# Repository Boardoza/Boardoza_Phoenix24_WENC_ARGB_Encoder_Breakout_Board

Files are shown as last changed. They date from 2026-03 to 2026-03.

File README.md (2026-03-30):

# Boardoza Phoenix24-WENC Breakout Board

The **Boardoza Phoenix-24WENC** is a versatile **addressable RGB LED breakout board** designed for interactive lighting applications. It integrates **24 addressable ARGB LEDs** along with a **rotary encoder**, enabling users to control lighting effects dynamically through physical input.

This board is well-suited for **user interfaces, decorative lighting, visual feedback systems, and interactive prototypes**. With support for **both CMOS and TTL logic levels** and flexible **THT and SMD connection options**, it can be easily integrated into a wide range of embedded systems, from quick prototyping setups to final product designs.

## [Click here to purchase!](https://www.ozdisan.com/ureticiler/boardoza)
| Front Side | Back Side |
|:---:|:---:|
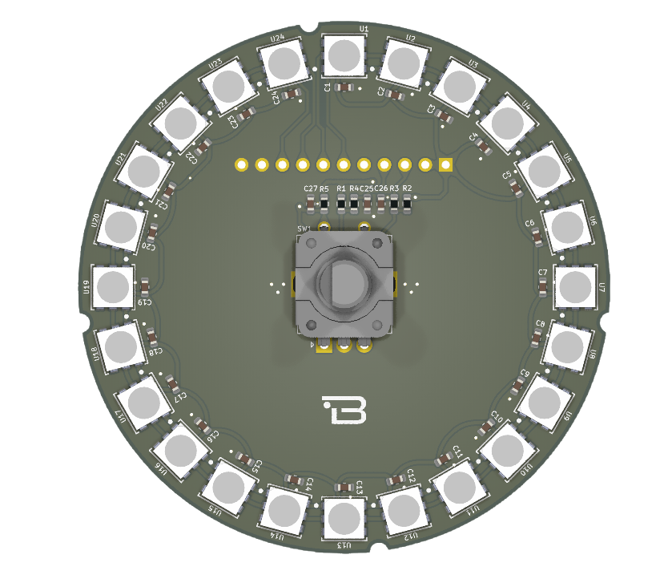
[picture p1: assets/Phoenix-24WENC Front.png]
Phoenix-24WENC Front
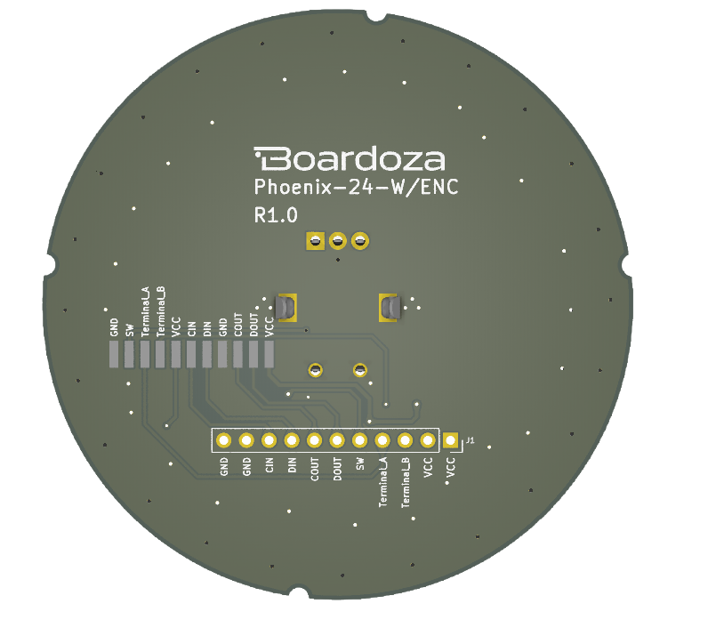
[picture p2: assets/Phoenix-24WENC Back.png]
Phoenix-24WENC Back
|  |  |

---

## Key Features

- **24 Addressable ARGB LEDs:** Provides vibrant, individually controllable RGB lighting for dynamic visual effects.  
- **Integrated Rotary Encoder Support:** Enables real-time and interactive LED control through user input.  
- **CMOS & TTL Logic Compatibility:** Ensures compatibility with a wide range of microcontrollers and logic systems.  
- **Flexible Signal Routing:** Includes DIN, CIN, DOUT, and COUT connections for easy signal chaining and management.  
- **Dual Connection Options:** Supports both THT (Through-Hole) and SMD (Surface-Mount) connections for flexible integration.  
- **Interactive Lighting Capabilities:** Ideal for user interfaces, visual feedback, and decorative lighting systems.  

---

## Technical Specifications

**Model:** Phoenix-24WENC   
**Manufacturer:** Boardoza  
**Functions:** Addressable RGB LED control with rotary encoder input  
**Input Voltage:** 3.3 V / 5 V  
**LED Model:** T3A33BRG-H9C0002X1U1930  
**Number of LEDs:** 24  
**LED Type:** Individually addressable RGB LEDs  
**Logic Compatibility:** TTL & CMOS  
**Data Interface:** Serial Data & Clock (DIN / CIN / DOUT / COUT)   
**Encoder Outputs:** Terminal A, Terminal B, Switch (Active Low)  
**Daisy-Chain Support:** Yes   
**Operating Temperature:** -40 °C to +85 °C  
**Board Dimensions:** 65.93 mm × 66.18 mm  

---

## Board Pinout

### **( J1 ) Power Connector**

| Pin Number | Pin Name | Description |
|:---:|:---:|---|
| 1 | VCC | Power Supply |

### **( J2 ) Power Connector**

| Pin Number | Pin Name | Description |
|:---:|:---:|---|
| 2 | VCC | Power Supply |

### **( J3 ) Encoder Terminal B**

| Pin Number | Pin Name | Description |
|:---:|:---:|---|
| 3 | Terminal_B | Encoder B terminal output |

### **( J4 ) Encoder Terminal A**

| Pin Number | Pin Name | Description |
|:---:|:---:|---|
| 4 | Terminal_A | Encoder A terminal output |

### **( J5 ) Encoder Switch**

| Pin Number | Pin Name | Description |
|:---:|:---:|---|
| 5 | SW | Encoder switch output (Active Low) |

### **( J6 ) Data Output**

| Pin Number | Pin Name | Description |
|:---:|:---:|---|
| 6 | DOUT | Series data output |

### **( J7 ) Clock Output**

| Pin Number | Pin Name | Description |
|:---:|:---:|---|
| 7 | COUT | Clock output |

### **( J8 ) Data Input**

| Pin Number | Pin Name | Description |
|:---:|:---:|---|
| 8 | DIN | Series data input |

### **( J9 ) Clock Input**

| Pin Number | Pin Name | Description |
|:---:|:---:|---|
| 9 | CIN | Clock input |

### **( J10 ) Ground**

| Pin Number | Pin Name | Description |
|:---:|:---:|---|
| 10 | GND | Ground |

### **( J11 ) Ground**

| Pin Number | Pin Name | Description |
|:---:|:---:|---|
| 11 | GND | Ground |

---

## Board Dimensions

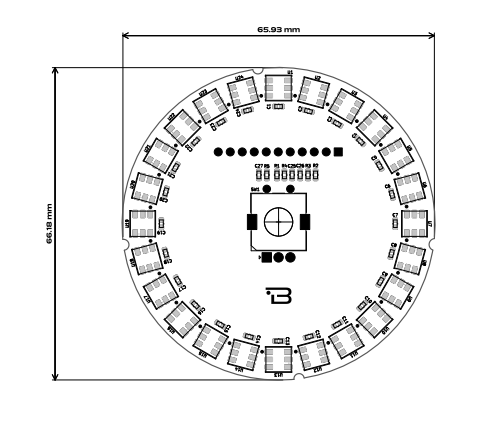
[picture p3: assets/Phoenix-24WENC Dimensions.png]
Board Dimensions


---

## Step Files

[Boardoza Phoenix-24WENC.step](./assets/Phoenix-24WENC%20Step.step)

---

## Datasheets

- [T3A33BRG ARGB LED Datasheet](./assets/Phoenix-24WENC%20Datasheet.pdf)  
- [Rotary Encoder Datasheet](./assets/Rotary%20Encoder%20Datasheet.pdf)

---

## Version History

- V1.0.0 – Initial Release

---

## Support

- If you have any questions or need support, please contact **support@boardoza.com**

---

## **License**

This repository contains both hardware and software components:

### **Hardware Design**

[][cc-by-sa]

All hardware design files are licensed under [Creative Commons Attribution-ShareAlike 4.0 International License][cc-by-sa].

[cc-by-sa]: http://creativecommons.org/licenses/by-sa/4.0/
[cc-by-sa-shield]: https://img.shields.io/badge/License-CC%20BY--SA%204.0-lightgrey.svg

### **Software/Firmware**

[][bsd]

All software and firmware are licensed under [BSD 3-Clause License][bsd].

[bsd]: https://opensource.org/licenses/BSD-3-Clause
[bsd-shield]: https://img.shields.io/badge/License-BSD%203--Clause-blue.svg

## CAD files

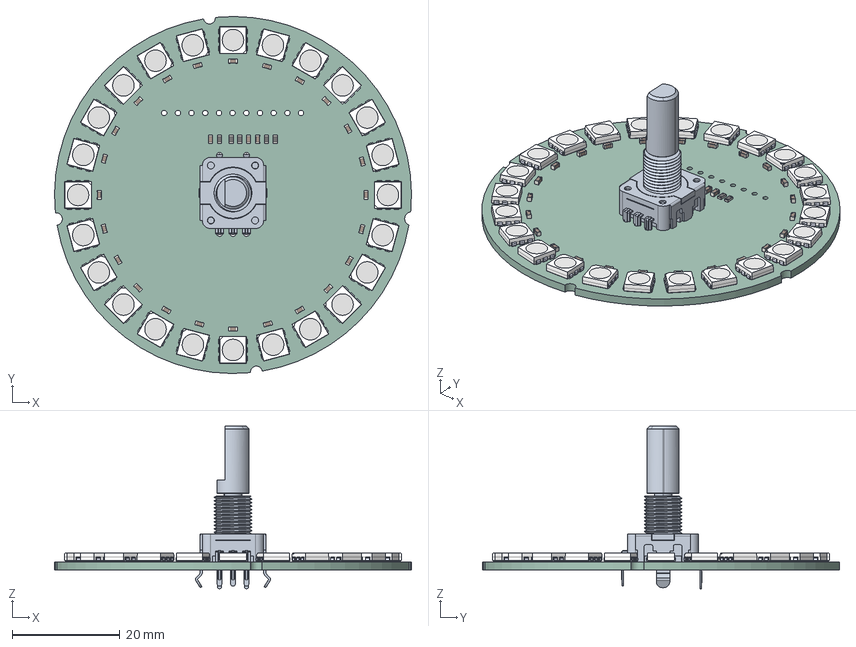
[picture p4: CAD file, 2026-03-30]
assets/Phoenix-24WENC Step.step
66.3 x 66.3 x 30.2 mm
C_0603_1608Metric x 27
LTST-G563ZEGBW--3DModel-STEP-510211 x 24
R_0603_1608Metric x 5
pec11r-4220f-s0012
B-Phoenix-24WENC-BRK_PCB

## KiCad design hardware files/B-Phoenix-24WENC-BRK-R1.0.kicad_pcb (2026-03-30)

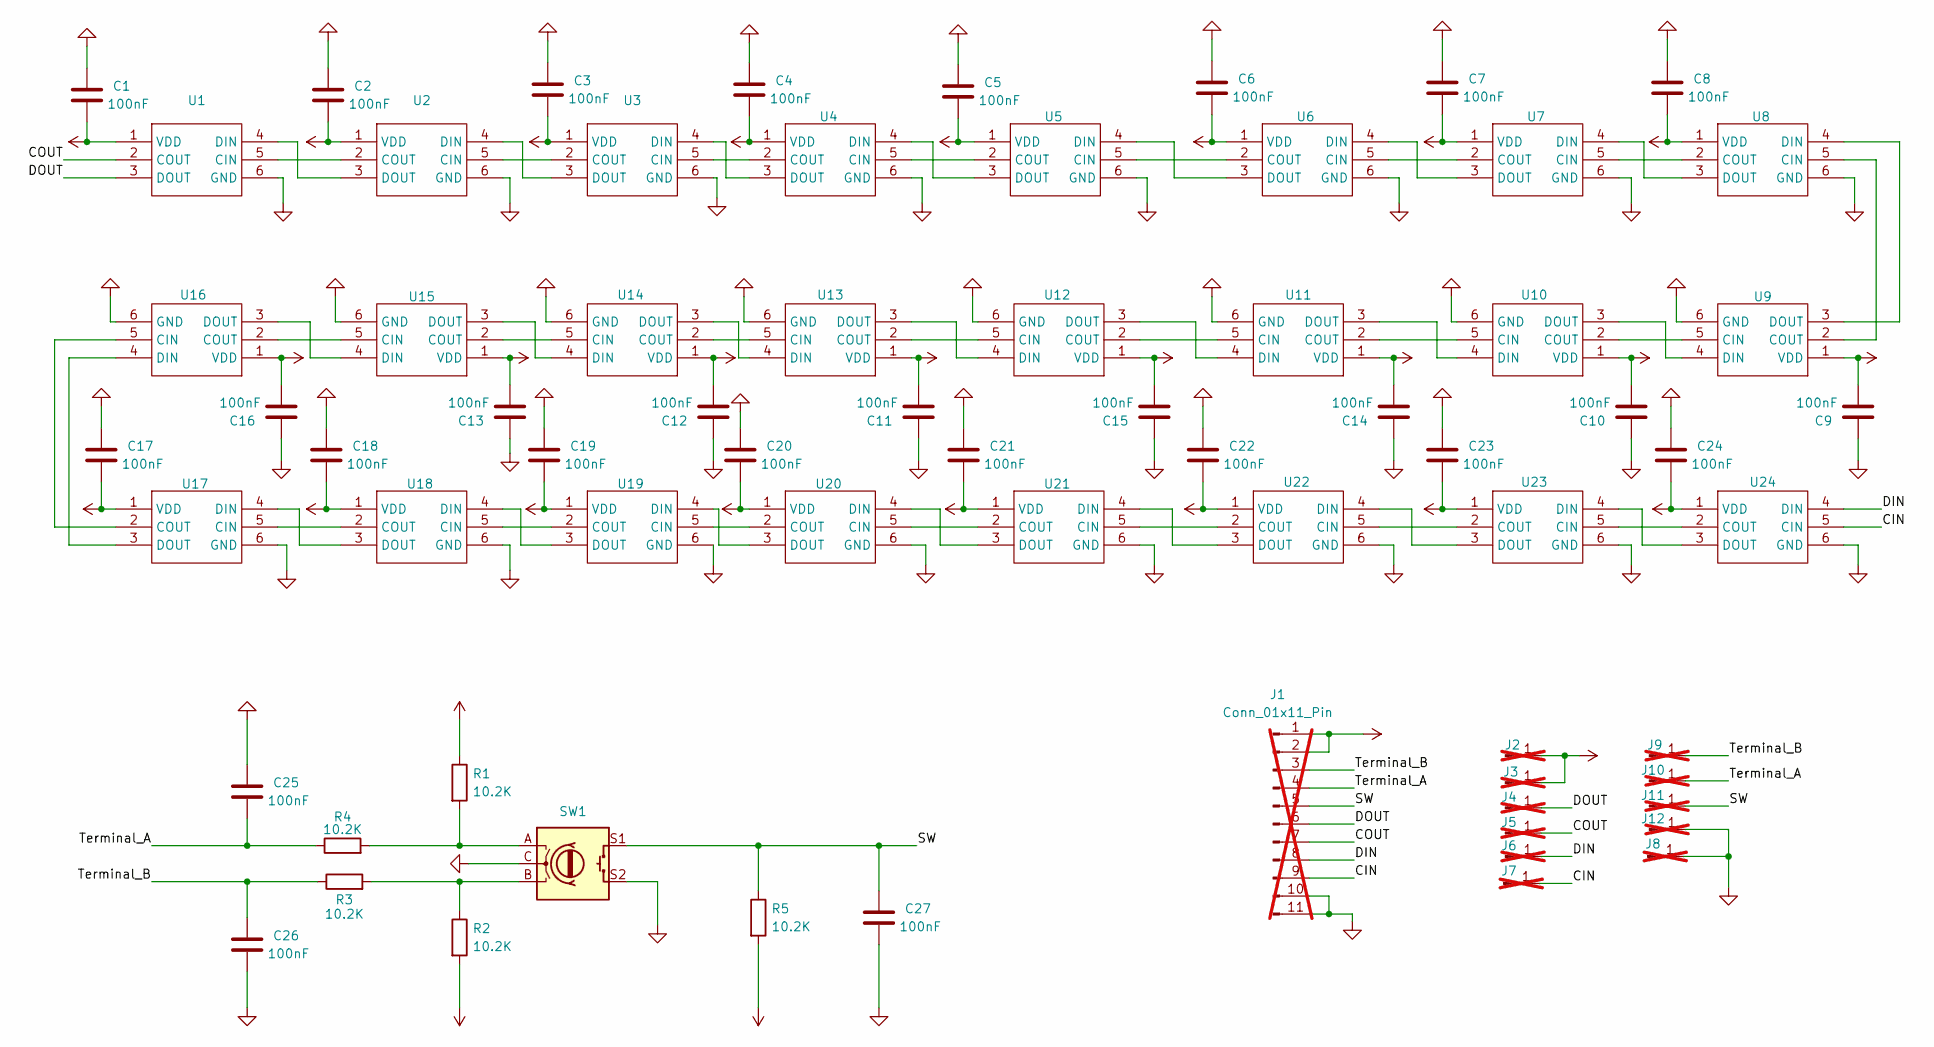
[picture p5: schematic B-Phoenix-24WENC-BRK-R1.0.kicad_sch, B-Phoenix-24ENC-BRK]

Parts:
C1, C2, C3, C4, C5, C6, C7, C8, C9, C10, C11, C12, C13, C14, C15, C16, C17, C18, C19, C20, C21, C22, C23, C24, C25, C26, C27: 100nF; C_0603_1608Metric; MPN MCF03KTB500104
J1: Conn_01x11_Pin; PinSocket_1x11_P2.54mm_Vertical; not fitted
J2, J3, J4, J5, J6, J7, J8, J9, J10, J11, J12: Conn_01x01_Pin; SolderWirePad_1x01_SMD_5x10mm; not fitted
R1, R2, R3, R4, R5: 10.2K; R_0603_1608Metric; MPN 0603SAF1022T5E
SW1: RotaryEncoder_Switch; L-KLS4-EC1123S-E-5A-F20; MPN L-KLS4-EC1123S-E-5A-F20
U1, U2, U3, U4, U5, U6, U7, U8, U9, U10, U11, U12, U13, U14, U15, U16, U17, U18, U19, U20, U21, U22, U23, U24: T3A33BRG-H9C0002X1U1930_HVK; MPN T3A33BRG-H9C0002X1U1930

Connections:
/CIN: J1.9, J7.1, U24.5 (CIN)
/COUT: J1.7, J5.1, U1.2 (COUT)
/DIN: J1.8, J6.1, U24.4 (DIN)
/DOUT: J1.6, J4.1, U1.3 (DOUT)
/SW: C27.1, J1.5, J11.1, R5.1, SW1.S1
/Terminal_A: C25.2, J1.4, J10.1, R4.1
/Terminal_B: C26.1, J1.3, J9.1, R3.1
GND: C1.1, C2.1, C3.1, C4.1, C5.1, C6.1, C7.1, C8.1, C9.1, C10.1, C11.1, C12.1, C13.1, C14.1, C15.1, C16.1, C17.1, C18.1, C19.1, C20.1, C21.1, C22.1, C23.1, C24.1, C25.1, C26.2, C27.2, J1.10, J1.11, J8.1, J12.1, SW1.C, SW1.MP, SW1.S2, U1.6 (GND), U2.6 (GND), U3.6 (GND), U4.6 (GND), U5.6 (GND), U6.6 (GND), U7.6 (GND), U8.6 (GND), U9.6 (GND), U10.6 (GND), U11.6 (GND), U12.6 (GND), U13.6 (GND), U14.6 (GND), U15.6 (GND), U16.6 (GND), U17.6 (GND), U18.6 (GND), U19.6 (GND), U20.6 (GND), U21.6 (GND), U22.6 (GND), U23.6 (GND), U24.6 (GND)
unnamed: R1.2, R4.2, SW1.A
unnamed: R2.1, R3.2, SW1.B
unnamed: U1.5 (CIN), U2.2 (COUT)
unnamed: U1.4 (DIN), U2.3 (DOUT)
unnamed: U2.5 (CIN), U3.2 (COUT)
unnamed: U2.4 (DIN), U3.3 (DOUT)
unnamed: U3.5 (CIN), U4.2 (COUT)
unnamed: U3.4 (DIN), U4.3 (DOUT)
unnamed: U4.5 (CIN), U5.2 (COUT)
unnamed: U4.4 (DIN), U5.3 (DOUT)
unnamed: U5.5 (CIN), U6.2 (COUT)
unnamed: U5.4 (DIN), U6.3 (DOUT)
unnamed: U6.5 (CIN), U7.2 (COUT)
unnamed: U6.4 (DIN), U7.3 (DOUT)
unnamed: U7.5 (CIN), U8.2 (COUT)
unnamed: U7.4 (DIN), U8.3 (DOUT)
unnamed: U8.5 (CIN), U9.2 (COUT)
unnamed: U8.4 (DIN), U9.3 (DOUT)
unnamed: U10.5 (CIN), U11.2 (COUT)
unnamed: U9.5 (CIN), U10.2 (COUT)
unnamed: U10.4 (DIN), U11.3 (DOUT)
unnamed: U9.4 (DIN), U10.3 (DOUT)
unnamed: U11.5 (CIN), U12.2 (COUT)
unnamed: U11.4 (DIN), U12.3 (DOUT)
unnamed: U12.5 (CIN), U13.2 (COUT)
unnamed: U12.4 (DIN), U13.3 (DOUT)
unnamed: U13.5 (CIN), U14.2 (COUT)
unnamed: U13.4 (DIN), U14.3 (DOUT)
unnamed: U14.5 (CIN), U15.2 (COUT)
unnamed: U14.4 (DIN), U15.3 (DOUT)
unnamed: U15.5 (CIN), U16.2 (COUT)
unnamed: U15.4 (DIN), U16.3 (DOUT)
unnamed: U16.5 (CIN), U17.2 (COUT)
unnamed: U16.4 (DIN), U17.3 (DOUT)
unnamed: U17.5 (CIN), U18.2 (COUT)
unnamed: U17.4 (DIN), U18.3 (DOUT)
unnamed: U18.5 (CIN), U19.2 (COUT)
unnamed: U18.4 (DIN), U19.3 (DOUT)
unnamed: U19.5 (CIN), U20.2 (COUT)
unnamed: U19.4 (DIN), U20.3 (DOUT)
unnamed: U20.5 (CIN), U21.2 (COUT)
unnamed: U20.4 (DIN), U21.3 (DOUT)
unnamed: U21.5 (CIN), U22.2 (COUT)
unnamed: U21.4 (DIN), U22.3 (DOUT)
unnamed: U22.5 (CIN), U23.2 (COUT)
unnamed: U22.4 (DIN), U23.3 (DOUT)
unnamed: U23.5 (CIN), U24.2 (COUT)
unnamed: U23.4 (DIN), U24.3 (DOUT)
VCC: C1.2, C2.2, C3.2, C4.2, C5.2, C6.2, C7.2, C8.2, C9.2, C10.2, C11.2, C12.2, C13.2, C14.2, C15.2, C16.2, C17.2, C18.2, C19.2, C20.2, C21.2, C22.2, C23.2, C24.2, J1.1, J1.2, J2.1, J3.1, R1.1, R2.2, R5.2, U1.1 (VDD), U2.1 (VDD), U3.1 (VDD), U4.1 (VDD), U5.1 (VDD), U6.1 (VDD), U7.1 (VDD), U8.1 (VDD), U9.1 (VDD), U10.1 (VDD), U11.1 (VDD), U12.1 (VDD), U13.1 (VDD), U14.1 (VDD), U15.1 (VDD), U16.1 (VDD), U17.1 (VDD), U18.1 (VDD), U19.1 (VDD), U20.1 (VDD), U21.1 (VDD), U22.1 (VDD), U23.1 (VDD), U24.1 (VDD)

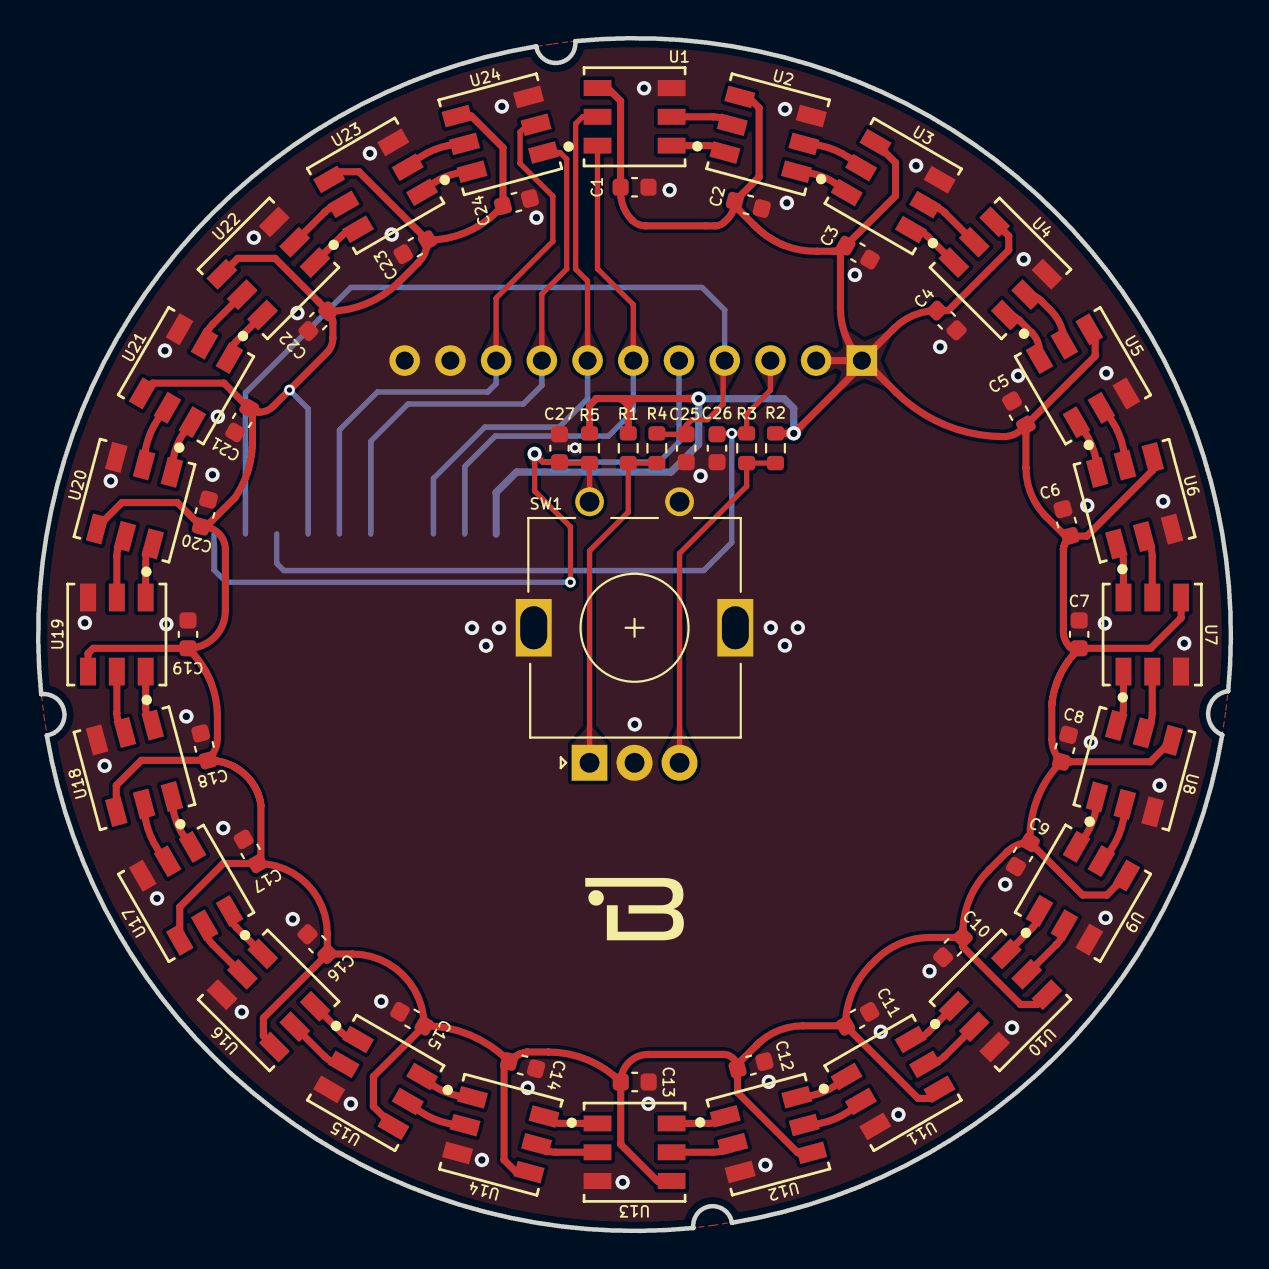
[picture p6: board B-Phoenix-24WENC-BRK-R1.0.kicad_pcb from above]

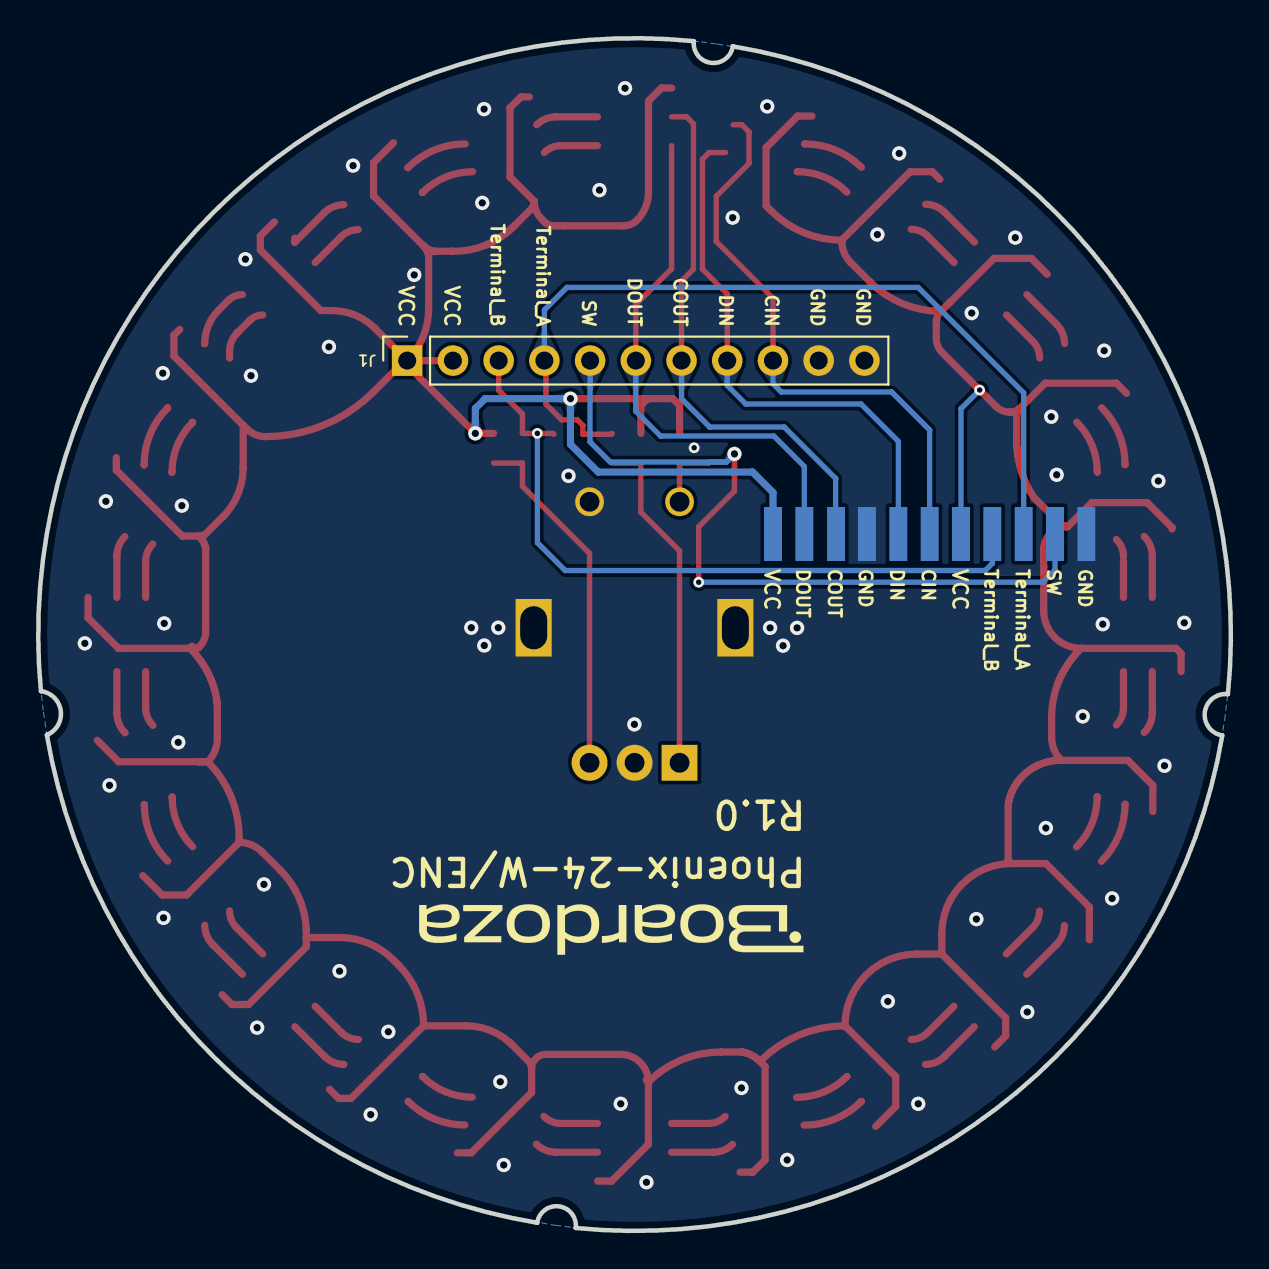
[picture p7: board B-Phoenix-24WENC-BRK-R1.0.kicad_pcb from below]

Board: 2 copper layers, 66.3 x 66.3 mm, 69 parts (12 on the bottom side), 57 nets.

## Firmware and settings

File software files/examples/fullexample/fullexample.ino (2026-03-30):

#include "EC1101S.h"
#include "T3A33BRG.h"

// Rotary Encoder Pins
#define TERMINAL_A 33
#define TERMINAL_B 21
#define SW         22

// LED Control Pins
#define DATA_PIN   25  // Suitable output pin
#define CLOCK_PIN  26  // Suitable output pin

// Create objects
EC1101S encoder(TERMINAL_A, TERMINAL_B, SW);
T3A33BRG ledController(DATA_PIN, CLOCK_PIN);

// Maximum number of LEDs
const uint8_t LED_COUNT = 12; // Total number of LEDs
uint8_t currentLED = 0;      // Index of the LED that is lit
uint8_t turnCounter = 0;     // Counter for 5 rotations
int8_t lastCount=0;
int8_t currentCount=0; 

/**
 * @brief Lights up a specific LED and turns off the rest.
 *
 * This function lights up the LED at the specified index while turning off
 * all the other LEDs. The `ledIndex` is wrapped around the maximum LED count (12)
 * using the modulo operation. 
 *
 * @param ledIndex The index of the LED to light up (0-based).
 *
 * The function sends the following commands:
 * - A reset command to turn off all LEDs.
 * - Commands to light up the specific LED and turn off others.
 * - A final command to ensure all LEDs are turned off at the end of the operation.
 *
 * Example usage:
 * @code
 * lightUpLED(5);  // Lights up the 5th LED.
 * @endcode
 */
void lightUpLED(uint8_t ledIndex) {
    uint8_t mode = ledIndex % 12;
    ledController.send32Bit(0, 0, 0, 0, 0);
    for (uint8_t i = 0; i <= LED_COUNT; i++) {
        if (i == mode) {
                ledController.send32Bit(0x07, 1, 0, 0, 255); // Turn on the LED
        } 
        else {
            ledController.send32Bit(0x07, 0, 0, 0, 0); // Turn off
        }
    }
   ledController.send32Bit(0x07, 31, 255, 255, 255); // Turn off   
}

/**
 * @brief Turns on LEDs with random colors and optionally turns them off.
 *
 * This function lights up LEDs with random colors for a total of 12 iterations.
 * The `order` parameter determines the modulo value to calculate the mode.
 * The `on_off` parameter is used to control the state, but its functionality is not fully implemented in the current version.
 *
 * @param order Determines the mode based on modulo 12 operation.
 * @param on_off Not fully implemented, reserved for controlling on/off state.
 *
 * The function performs the following steps:
 * - Sends an initial reset command to turn off all LEDs.
 * - Iterates through 12 LEDs, turning each one on with a random RGB value.
 * - Sends a final command to turn off all LEDs.
 *
 * Example usage:
 * @code
 * randomLEDOn(5, 1);  // Lights up LEDs with random colors.
 * @endcode
 */                                                                                                                                                                                                                                                                                                                                                                          
void randomLEDOn(uint8_t order, uint8_t on_off)
{
uint8_t i=0; 
uint8_t mode=order%12;
ledController.send32Bit(0, 0, 0, 0, 0); 
while (i<=12)
    {
    i++; 
    ledController.send32Bit(0x07, 1, (rand()%255), (rand()%255), (rand()%255));          
    }
ledController.send32Bit(0x07, 31, 255, 255, 255); // Turn off
}

void setup() {
    Serial.begin(115200);

    // Initialize the encoder and LED controller
    encoder.begin();
    ledController.begin();

    // Reset all LEDs initially
    ledController.send32Bit(0, 0, 0, 0, 0);
}

void loop() {

    encoder.update();

    currentCount = encoder.getCount();

    if (currentCount != lastCount) {
        //randomLEDOn(currentCount, 1);     // Uncomment this line if you want to use the randomLEDOn function
        // Determine direction
        if (currentCount > lastCount) {
            turnCounter++; // Clockwise -> Forward
            //if (turnCounter >= 1 && currentLED < LED_COUNT) { // use this block if you want to light all leds at the same time
            if (turnCounter >= 1 ) {                            // use this block if you want to light leds one by one
                currentLED++; // Light up the next LED
                turnCounter = 0; // Reset the counter
            }
        } else {
            turnCounter++; // Counter-clockwise -> Backward
            if (turnCounter >= 1 && currentLED > 0) {
                currentLED--; // Turn off the previous LED
                turnCounter = 0; // Reset the counter
            }
        }
    Serial.println(currentCount);

    // Change the LED
    lightUpLED(currentLED);     // Comment this line if you want to use the randomLEDOn function
    lastCount = currentCount;
    }
}

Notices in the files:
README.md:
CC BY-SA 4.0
